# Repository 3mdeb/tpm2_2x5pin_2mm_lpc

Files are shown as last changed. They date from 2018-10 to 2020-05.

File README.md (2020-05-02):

# TPM2 module schematics

TPM2 module PCB project for platforms with 2x5 pin, 2mm pitch LPC header was
created for the Librebox platform under contract work from Libretrend company.

## Description

Trusted Platform Module compatible with 2x5p LPC header (populated on Librebox
platform) can be used in:

* disk encryption
* password protection
* platform integrity and other security issues

TPM module for Librebox features:

* TPM SLB9665TT20FW561XUMA1
* Operating voltage 3-3.3V
* Meeting Intel TXT, Microsoft Windows and Google Chromebook certification
  criteria for successful platform qualification
* True Random Number Generator (TRNG)
* Full personalization with Endorsement Key (EK) and EK certificate
* Supports the LPC interface

## Pinout

The pin layout is unique therefore users of other platforms should first make
sure that the pinout corresponds to the one from the image below:

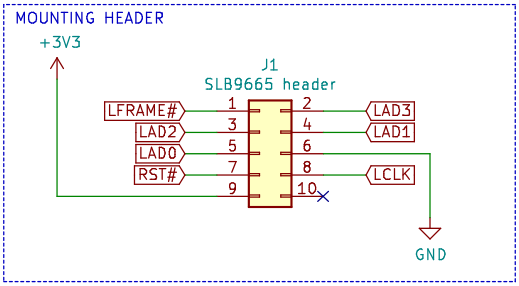
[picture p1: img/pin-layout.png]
tpm2-2x5pin-2mm-lpc-pinout


## License

* Hardware is licensed under [CERN license](LICENSE.txt)
* Documentation is licensed under [CC BY-SA license](https://creativecommons.org/licenses/by-sa/2.0/)

## Where can I buy this product?

If you are not the enthusiast of DYI, then the plug and play product can be
bought in the:

* [Libretrend shop](https://libretrend.com/specs/librebox)
* [3mdeb shop](https://shop.3mdeb.com/product/tpm2-module-for-librebox/)

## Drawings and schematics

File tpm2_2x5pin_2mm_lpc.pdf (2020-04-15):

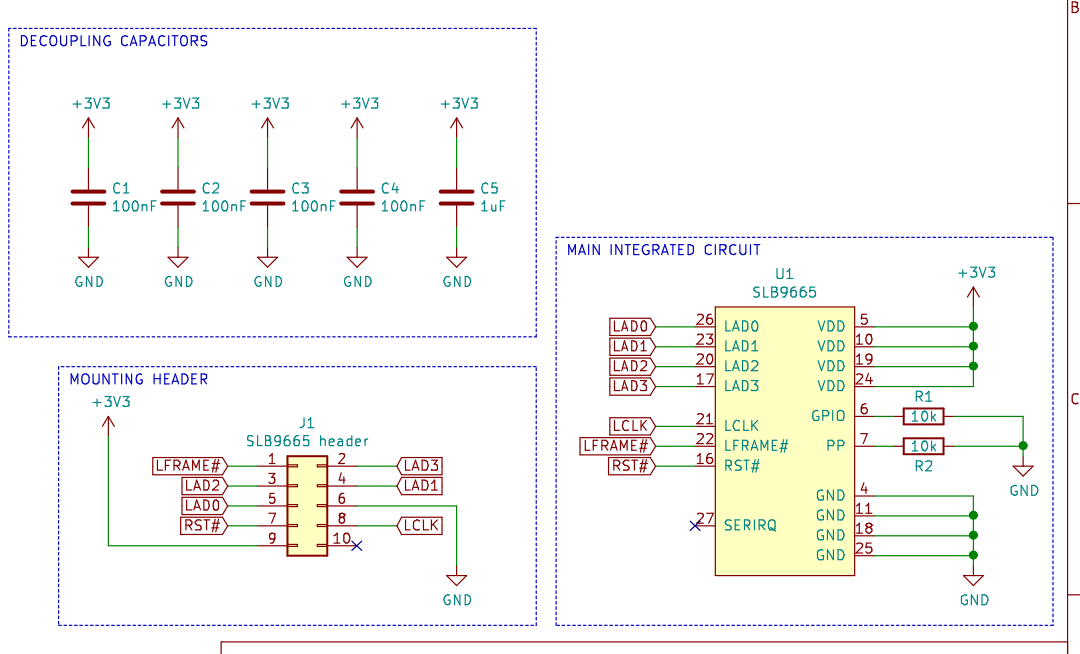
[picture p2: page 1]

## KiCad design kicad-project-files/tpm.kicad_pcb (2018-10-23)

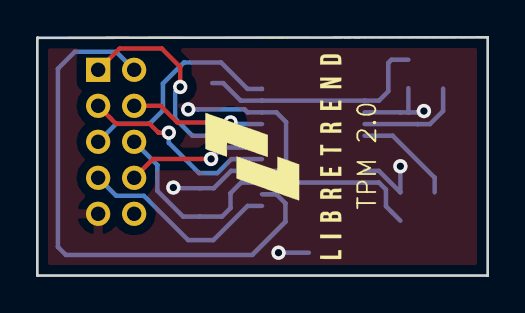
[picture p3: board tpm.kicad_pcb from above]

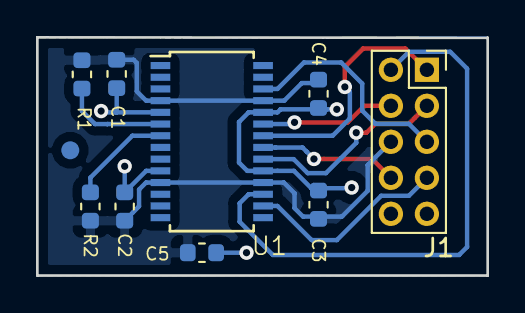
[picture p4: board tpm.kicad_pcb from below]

Board: 2 copper layers, 25.0 x 13.2 mm, 9 parts (9 on the bottom side), 11 nets.

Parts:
C1, C2, C3, C4: 100nF; C_0603_1608Metric
C5: 1uF; C_0603_1608Metric
J1: SLB9665 header; PinSocket_2x05_P2.00mm_Vertical
R1, R2: 10k; R_0603_1608Metric
U1: SLB9665; TSSOP-28_4.4x9.7mm_P0.65mm

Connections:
+3V3: C1.1, C2.1, C3.1, C4.1, C5.1, J1.9, U1.5, U1.10, U1.19, U1.24
GND: C1.2, C2.2, C3.2, C4.2, C5.2, J1.6, R1.1, R2.1, U1.4, U1.11, U1.18, U1.25
LAD0: J1.5, U1.26
LAD1: J1.4, U1.23
LAD2: J1.3, U1.20
LAD3: J1.2, U1.17
LCLK: J1.8, U1.21
LFRAME#: J1.1, U1.22
unnamed: R1.2, U1.6
unnamed: R2.2, U1.7
RST#: J1.7, U1.16

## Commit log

2018-09-24 Created initial version of the LPC bus
    [tpm.kicad_pcb, tpm.sch]
2018-10-12 Changed: size of the Libretrend logo
    [tpm.sch]
2018-10-22 Shorted +3v3 pins
    [tpm.kicad_pcb]
